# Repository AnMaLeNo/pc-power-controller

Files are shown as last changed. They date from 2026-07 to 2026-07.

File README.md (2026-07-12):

# 🔌 PC Power Controller (IoT)










Un système IoT complet permettant de contrôler à distance l'alimentation d'un PC fixe. Ce projet relie une interface de commande web/API à l'électronique physique de la carte mère du PC grâce à une architecture distribuée et conteneurisée.

## Description

Ce projet permet d'allumer, d'éteindre ou de forcer l'arrêt d'un ordinateur à distance en simulant une pression sur le bouton d'alimentation physique du boîtier. Il a été conçu avec une approche microservices pour garantir la fiabilité et la rapidité des commandes.

**Fonctionnalités principales :**
- **Contrôle physique sécurisé :** Utilisation d'un optocoupleur connecté à un ESP8266 pour isoler électriquement le circuit du microcontrôleur de celui de la carte mère.
- **Communication Temps Réel :** Utilisation d'un broker MQTT (Eclipse Mosquitto) pour transmettre les commandes de l'API vers le microcontrôleur presque instantanément.
- **API REST Robuste :** Développée avec Fastify pour des performances optimales, incluant la validation des schémas de requêtes.
- **Interface Web Typée :** Application React + TypeScript construite avec Vite, proposant un pupitre de commande adapté au contrôle physique du PC.
- **Déploiement Facilité :** Conteneurisation de la stack (Frontend + API) via Docker Compose. Le broker MQTT est une infrastructure partagée du Raspberry, hébergée dans son propre dépôt.

## Architecture du Système

Le projet est divisé en quatre composants majeurs :
1. **Frontend Web (React / TypeScript / Vite) :** Fournit une interface de commande responsive, servie par Nginx en production et reliée à l'API via un proxy `/api`.

2. **Backend API (Node.js / Fastify) :** Reçoit les requêtes HTTP (ex: `SHORT_PRESS` ou `LONG_PRESS`) et les publie sur le topic MQTT `bureau/pc/power/set`.
3. **Broker MQTT (Eclipse Mosquitto) :** Agit comme un intermédiaire léger pour distribuer les messages entre l'API et le hardware. C'est une infrastructure **partagée** entre tous les projets IoT du Raspberry (un seul broker par machine) : il vit dans le dépôt `~/mosquitto`, et ce projet s'y connecte en simple client via `host.docker.internal:1883` (surchargeable par `.env` : `MQTT_HOST`, `MQTT_PORT`).
4. **Firmware ESP8266 (C++ / Arduino) :** Connecté au réseau WiFi local, il s'abonne au topic MQTT. À la réception d'un message, il déclenche une impulsion (High/Low) d'une durée spécifique (300ms pour un appui court, 6000ms pour un appui long) sur la broche `D1` reliée à l'optocoupleur.

## Installation & Lancement

### 1. Configuration du Hardware (ESP8266)
Le code source se trouve dans le dossier `esp8266/`. Le projet est configuré avec **PlatformIO**.
- Copiez `config.ini.exemple` vers `config.ini` et ajoutez vos identifiants WiFi ainsi que l'IP de votre serveur MQTT.
- Compilez et téléversez le code C++ sur votre Wemos D1 Mini / ESP8266.

### 2. Prérequis : le broker MQTT partagé
Le broker Mosquitto n'est plus embarqué dans ce projet : c'est une infrastructure commune au Raspberry, gérée dans le dépôt `~/mosquitto`. Démarrez-le d'abord s'il ne tourne pas déjà :

```bash
cd ~/mosquitto
docker compose up -d
```

### 3. Lancement de la stack Docker
Assurez-vous d'avoir [Docker](https://www.docker.com/) et Docker Compose installés sur votre machine ou votre serveur cible (ex: Raspberry Pi).

```bash
# Clonez le dépôt
git clone https://github.com/AnMaLeNo/pc-power-controller.git
cd pc-power-controller

# Lancez les conteneurs en tâche de fond
docker compose up -d --build
```

L'interface web est disponible sur `http://localhost:18080`. En mode développement avec l'override Docker Compose, Vite est aussi exposé sur `http://localhost:5174`.

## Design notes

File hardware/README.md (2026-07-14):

# 🔧 Hardware — carte optocoupleur (KiCad)

PCB « carrier » compact (**54,7 × 35,2 mm**) pour le contrôleur
d'alimentation : un **Wemos D1 Mini** pilote un **PC817** à travers **R1
(330 Ω)** ; la sortie de l'optocoupleur va sur **2 pastilles à souder** (J1)
reliées par fils au header `PWR_SW` de la carte mère. Isolation galvanique
totale entre l'ESP8266 et le PC. Deux pastilles supplémentaires (**J2**)
permettent d'alimenter le module en 5 V sans passer par l'USB.

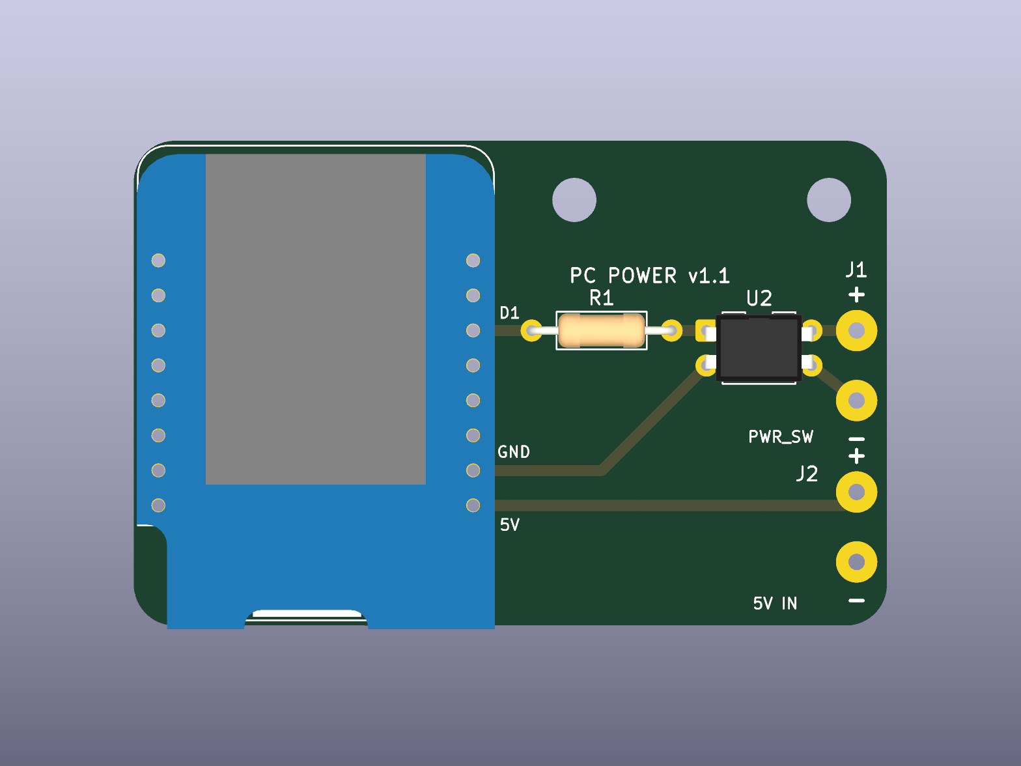
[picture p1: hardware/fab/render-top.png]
Rendu du dessus


## Contenu

| Fichier | Rôle |
|---|---|
| `pc-power-controller.kicad_pro/sch/pcb` | Projet KiCad (s'ouvre dans KiCad ≥ 9) |
| `pc_power.kicad_sym`, `pc_power.pretty/` | Symboles & empreintes du projet (copies figées des libs officielles 9.0.9.1) |
| `generate/gen_sch.py` | Génère le schéma (Python pur) |
| `generate/gen_pcb.py` | Génère le PCB routé (API `pcbnew` du flatpak KiCad) |
| `fab/` | Sorties : Gerbers + perçage (`pc-power-controller-gerbers.zip`), BOM, rendus, rapports ERC/DRC |

## Nomenclature (BOM)

| Réf. | Composant | Empreinte |
|---|---|---|
| U1 | Wemos D1 Mini (ESP8266) | 2 rangées de 8 broches, pas 2,54 mm — prévoir des **headers femelles** |
| U2 | PC817 (Sharp) | DIP-4 |
| R1 | Résistance 330 Ω, 1/4 W axiale | DIN0207, pas 10,16 mm |
| J1 | Sortie PWR_SW | 2 pastilles Ø3 mm, perçage 1,2 mm, pas 5,08 mm |
| J2 | Entrée alim 5V/GND | 2 pastilles Ø3 mm, perçage 1,2 mm, pas 5,08 mm |
| H1-H2 | Vis M3 | 2 trous de fixation Ø3,2 mm |

## Câblage vers le PC

**J1 (PWR_SW)** :
- Pastille **`+`** → broche `PWR_SW` (signal) du header F_PANEL de la carte mère
- Pastille **`−`** → broche `GND` du même header
- La polarité **compte** (collecteur/émetteur du PC817). En cas de doute : la
  broche `+` du header carte mère est celle qui n'est pas au GND du boîtier.

**Alimentation, au choix** :
- par le **port USB** du module (bord bas de la carte), **ou**
- par **J2** : pastille `+` → 5 V, pastille `−` → GND (ex. depuis le standby
  5VSB d'une alim ATX ou un chargeur sacrifié).
- ⚠️ **Jamais les deux en même temps** : la broche 5V du D1 Mini est reliée en
  direct au VBUS de l'USB (pas de diode sur la plupart des clones).

## Régénérer les fichiers

```bash
cd hardware
python3 generate/gen_sch.py
flatpak run --command=python3 org.kicad.KiCad generate/gen_pcb.py
```

## Vérifier et exporter

```bash
k="flatpak run --command=kicad-cli org.kicad.KiCad"
$k sch erc --severity-all --format report -o fab/erc.rpt pc-power-controller.kicad_sch
$k pcb drc --schematic-parity --severity-all --format report -o fab/drc.rpt pc-power-controller.kicad_pcb
$k pcb render --side top -o fab/render-top.png pc-power-controller.kicad_pcb
$k pcb export gerbers --layers F.Cu,B.Cu,F.Mask,B.Mask,F.SilkS,B.SilkS,Edge.Cuts -o fab/gerbers/ pc-power-controller.kicad_pcb
$k pcb export drill --format excellon --excellon-units mm --drill-origin absolute -o fab/gerbers/ pc-power-controller.kicad_pcb
```

État actuel : **ERC 0 erreur / 0 warning, DRC 0 violation, parité schéma↔PCB OK.**

## Commander (ex. JLCPCB)

1. <https://jlcpcb.com> → *Order now* → uploader `fab/pc-power-controller-gerbers.zip`
2. Paramètres par défaut : 2 couches, 1,6 mm, HASL — carte 54,7 × 35,2 mm
3. ~2-5 € les 5 exemplaires, hors port. Soudure à la main (tout traversant).

## Notes de conception

- Piste GND : pad 10 du module (7ᵉ pastille, colonne droite) ; signal : pad 14
  (`D1`/GPIO5, 3ᵉ pastille) — cohérent avec `esp8266/src/main.cpp` (`pinOpto = D1`).
- Le retour GND de J2 passe en **face arrière** (seule piste au dos) ; les pads
  traversants relient les deux couches, aucun via.
- La zone antenne du module (haut gauche) est **sans cuivre ni piste** ; ne
  rien ajouter dans cette zone si la carte évolue.
- Prévu pour un 2ᵉ étage plus tard (lecture de l'état d'alim du PC) : les
  GPIO restants du module sont accessibles sur les pastilles du support.

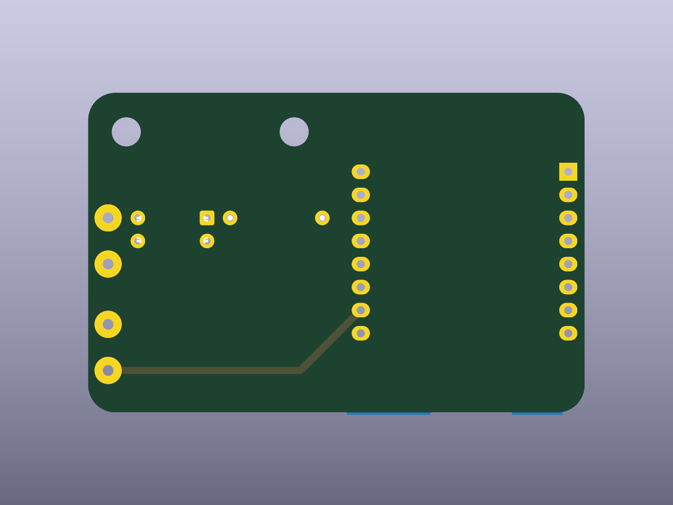
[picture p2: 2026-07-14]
hardware/fab/render-bottom.png

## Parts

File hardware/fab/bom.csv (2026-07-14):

Reference | Valeur | Empreinte | Qte
J1 | PWR_SW | pc_power:SolderWirePad_1x02_P5.08mm | 1
J2 | 5V_IN | pc_power:SolderWirePad_1x02_P5.08mm | 1
R1 | 330R | pc_power:R_Axial_DIN0207_L6.3mm_D2.5mm_P10.16mm_Horizontal | 1
U1 | WEMOS_D1_mini | pc_power:WEMOS_D1_mini_light | 1
U2 | PC817 | pc_power:DIP-4_W7.62mm | 1

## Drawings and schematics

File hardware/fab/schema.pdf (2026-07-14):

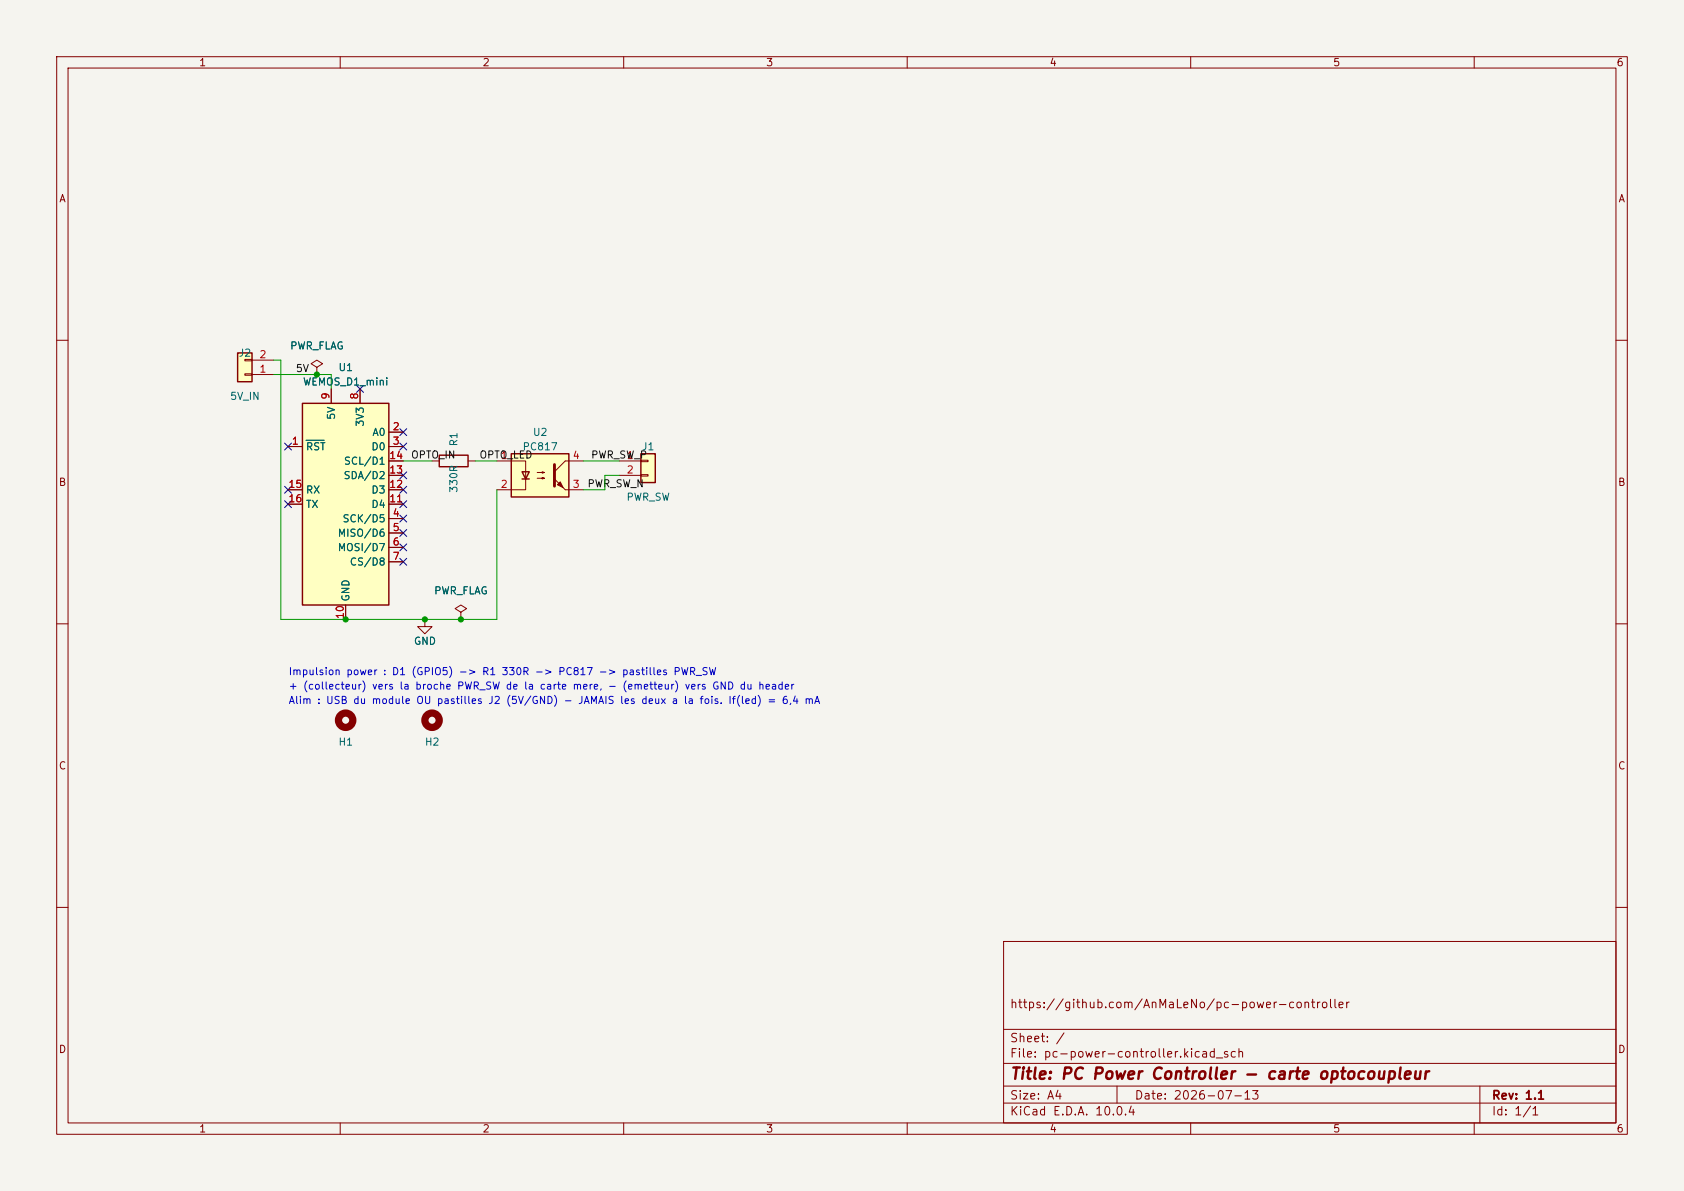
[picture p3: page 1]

Alim : USB du module OU pastilles J2 (5V/GND) - JAMAIS les deux a la fois. If(led) = 6,4 mA U1 WEMOS_D1_mini RST 1

8 5V 9 GND 10 D4 11 D3 12 SDA/D2 13 SCL/D1 14 RX 15

RST 1
PWR_SW_P + (collecteur) vers la broche PWR_SW de la carte mere, - (emetteur) vers GND du header

Sheet: /
File: pc-power-controller.kicad_sch
Title: PC Power Controller - carte optocoupleur

Size: A4 | Rev: 1.1
KiCad E.D.A. 10.0.4 | Id: 1/1

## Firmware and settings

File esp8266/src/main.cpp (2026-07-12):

#include <Arduino.h>
#include <ESP8266WiFi.h>
#include <PubSubClient.h>

// Configuration
const char* ssid = WIFI_SSID;
const char* password = WIFI_PASS;
const char* mqtt_server = MQTT_SERVER;
const uint16_t mqtt_port = 1883;

// Topiques MQTT
const char* topic_command = "bureau/pc/power/set";
const char* topic_state   = "bureau/pc/power/log";
// Présence : "online" publié à la connexion, "offline" déposé par le broker
// via le Last Will si la liaison meurt (~1,5x le keepalive). Retenu, pour que
// tout abonné connaisse l'état courant dès sa souscription.
const char* topic_status  = "bureau/pc/power/status";

// Hardware
const int pinOpto = D1;
const int pinLed = LED_BUILTIN;

WiFiClient wifiNetworkClient;
PubSubClient mqttClient(wifiNetworkClient);

// Impulsion matérielle : la fin est déléguée au timer1 (ISR one-shot), donc la
// durée reste bornée même si la boucle principale est bloquée (ex. connect()
// MQTT pendant une panne réseau). Contrainte : timer1 doit rester libre, donc
// pas d'analogWrite/tone/Servo dans ce firmware.
volatile bool pulseActive = false;
const uint32_t SHORT_PRESS_DURATION = 300;
const uint32_t LONG_PRESS_DURATION = 6000;
// Action en cours, corrélée à l'ACK pulse_end. Littéraux uniquement : l'ISR
// recopie le pointeur, jamais le contenu.
const char* pulseAction = "";
// Fin d'impulsion signalée par l'ISR ; l'ACK MQTT est publié depuis la boucle
// principale (interdiction de publier depuis une ISR).
const char* volatile endedAction = "";
volatile bool pulseEndPending = false;

// Définition des états de l'automate réseau (FSM)
enum NetworkState {
    NET_INIT,
    NET_WIFI_CONNECTING,
    NET_WIFI_WAIT,
    NET_MQTT_CONNECTING,
    NET_CONNECTED,
    NET_COOLDOWN
};

NetworkState netState = NET_INIT;
uint32_t lastNetworkAttempt = 0;
// Timeout d'association WiFi + DHCP : assez large pour les box lentes (sinon
// l'ESP abandonne avant la fin de la négociation et boucle indéfiniment).
const uint32_t WIFI_CONNECT_TIMEOUT = 20000;
// Délai de temporisation avant une nouvelle tentative après un échec.
const uint32_t COOLDOWN_DURATION = 5000;

// Dimensionné pour le plus long ACK JSON (pulse_start/end avec action + ts 32 bits).
char buffer[80];
const uint16_t MESSAGE_MAX_LENGTH = 20;

// Déclaration préalable des fonctions
void startPulse(uint32_t duration, const char* action);
void handlePulseAck();
void processNetworkFSM();

void callback(char* topic, byte* payload, unsigned int length) {
    char message[MESSAGE_MAX_LENGTH + 1];
    if (length > MESSAGE_MAX_LENGTH) {
        mqttClient.publish(topic_state, "{\"event\":\"error\",\"reason\":\"payload_too_large\"}");
        Serial.printf("payload trop grand, size: %d, max: %d\n", length, MESSAGE_MAX_LENGTH);
        return;
    }

    memcpy(message, payload, length);
    message[length] = '\0';
    Serial.printf("Message reçu [%s] %s\n", topic, message);

    if (strcmp(topic, topic_command) == 0) {
        if (strcmp(message, "SHORT_PRESS") == 0) {
            startPulse(SHORT_PRESS_DURATION, "SHORT_PRESS");
        } else if (strcmp(message, "LONG_PRESS") == 0) {
            startPulse(LONG_PRESS_DURATION, "LONG_PRESS");
        } else {
            mqttClient.publish(topic_state, "{\"event\":\"error\",\"reason\":\"unknown_command\"}");
            Serial.printf("Message [%s] inconnu\n", message);
        }
    }
}

// Fin d'impulsion en contexte d'interruption : s'exécute à l'échéance exacte,
// y compris pendant un appel réseau bloquant de la boucle principale.
IRAM_ATTR void onPulseEnd() {
    digitalWrite(pinOpto, LOW);
    digitalWrite(pinLed, HIGH);
    endedAction = pulseAction;
    pulseEndPending = true;
    pulseActive = false;
}

void startPulse(uint32_t duration, const char* action) {
    if (pulseActive) {
        mqttClient.publish(topic_state, "{\"event\":\"error\",\"reason\":\"pulse_already_active\"}");
        Serial.print("Pulse already active\n");
        return;
    }
    pulseAction = action;
    pulseActive = true;

    digitalWrite(pinOpto, HIGH);
    digitalWrite(pinLed, LOW);

    // One-shot timer1 en TIM_DIV256 : 80 MHz / 256 = 312,5 ticks/ms, d'où
    // ticks = ms * 625 / 2 (durées paires ici, division exacte). Max 23 bits
    // = ~26,8 s, largement au-dessus du LONG_PRESS.
    timer1_enable(TIM_DIV256, TIM_EDGE, TIM_SINGLE);
    timer1_write((duration * 625UL) / 2);

    // Publié après l'armement : un blocage réseau ne peut plus retarder la
    // libération de la broche, elle appartient désormais au timer.
    snprintf(buffer, sizeof(buffer),
             "{\"event\":\"pulse_start\",\"action\":\"%s\",\"ts\":%lu}", action, millis());
    mqttClient.publish(topic_state, buffer);
    Serial.print("Start pulse\n");
}

// Publie l'ACK de la fin d'impulsion signalée par l'ISR. Le ts est celui de la
// publication ; la broche, elle, a été libérée pile à l'échéance par le timer.
void handlePulseAck() {
    if (!pulseEndPending) return;
    pulseEndPending = false;

    if (mqttClient.connected()) {
        snprintf(buffer, sizeof(buffer),
                 "{\"event\":\"pulse_end\",\"action\":\"%s\",\"ts\":%lu}", endedAction, millis());
        mqttClient.publish(topic_state, buffer);
    }
    Serial.print("End pulse\n");
}

void processNetworkFSM() {
    uint32_t now = millis();

    switch (netState) {
        case NET_INIT:
            WiFi.persistent(false);
            WiFi.mode(WIFI_STA);
            WiFi.setAutoConnect(false);     // Désactivation de la FSM interne d'Espressif (L2)
            WiFi.setAutoReconnect(false);   // Reprise du contrôle logiciel absolu de la couche liaison
            netState = NET_WIFI_CONNECTING;
            break;

        case NET_WIFI_CONNECTING:
            Serial.printf("Connexion au WiFi: %s\n", ssid);
            WiFi.begin(ssid, password);
            lastNetworkAttempt = now;
            netState = NET_WIFI_WAIT;
            break;

        case NET_WIFI_WAIT:
            if (WiFi.status() == WL_CONNECTED) {
                Serial.printf("\nWiFi connecté. IP: %s\n", WiFi.localIP().toString().c_str());
                netState = NET_MQTT_CONNECTING;
            } else if (now - lastNetworkAttempt >= WIFI_CONNECT_TIMEOUT) {
                Serial.println("\nTimeout WiFi. Bascule en Cooldown.");
                WiFi.disconnect();
                lastNetworkAttempt = now;
                netState = NET_COOLDOWN;
            }
            break;

        case NET_MQTT_CONNECTING:
            if (WiFi.status() != WL_CONNECTED) {
                netState = NET_WIFI_CONNECTING;
                break;
            }

            {
                String clientId = "ESP8266Client-" + WiFi.macAddress();
                clientId.replace(":", "");
                Serial.printf("Tentative MQTT %s:%u\n", mqtt_server, mqtt_port);
                
                // Appel synchrone encapsulé - Blocage borné par le timeout LwIP/PubSubClient.
                // Le Last Will (QoS 1, retenu) est déposé auprès du broker à la connexion.
                if (mqttClient.connect(clientId.c_str(), topic_status, 1, true, "offline")) {
                    Serial.println("Connecté au serveur MQTT !");
                    // Message de naissance : annule l'éventuel "offline" retenu.
                    mqttClient.publish(topic_status, "online", true);
                    mqttClient.subscribe(topic_command);
                    netState = NET_CONNECTED;
                } else {
                    Serial.printf("Echec MQTT rc=%d. Bascule en Cooldown.\n", mqttClient.state());
                    lastNetworkAttempt = now;
                    netState = NET_COOLDOWN;
                }
            }
            break;

        case NET_CONNECTED:
            if (WiFi.status() != WL_CONNECTED || !mqttClient.connected()) {
                Serial.println("Perte de liaison (L2 ou L7).");
                netState = NET_COOLDOWN;
                lastNetworkAttempt = now;
            } else {
                mqttClient.loop(); // Traitement des buffers réseau entrants
            }
            break;

        case NET_COOLDOWN:
            // Interdiction stricte de toute opération réseau pendant la fenêtre de temporisation
            if (now - lastNetworkAttempt >= COOLDOWN_DURATION) {
                netState = (WiFi.status() == WL_CONNECTED) ? NET_MQTT_CONNECTING : NET_WIFI_CONNECTING;
            }
            break;
    }
}

void setup() {
    Serial.begin(115200);
    pinMode(pinOpto, OUTPUT);
    pinMode(pinLed, OUTPUT);
    
    // Initialisation de l'état nominal physique (Safe state)
    digitalWrite(pinOpto, LOW);
    digitalWrite(pinLed, HIGH);

    // Timer matériel dédié à la fin d'impulsion (one-shot armé par startPulse)
    timer1_isr_init();
    timer1_attachInterrupt(onPulseEnd);

    mqttClient.setServer(mqtt_server, mqtt_port);
    mqttClient.setCallback(callback);
}

void loop() {
    // Ordonnancement coopératif à complexité amortie O(1)
    handlePulseAck();      // Publication différée des ACK de fin d'impulsion
    processNetworkFSM();   // Traitement asynchrone non-bloquant du vecteur réseau
}

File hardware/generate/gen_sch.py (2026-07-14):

#!/usr/bin/env python3
"""Génère hardware/pc-power-controller.kicad_sch (format KiCad 9).

Circuit : D1 (GPIO5) -> R1 330R -> LED du PC817 ; sortie du PC817 -> 2 pastilles
à souder (PWR_SW) vers le header power de la carte mère.
Toutes les coordonnées sont en mm, alignées sur la grille 1,27 mm ; la
connectivité KiCad repose sur la coïncidence exacte des extrémités.
"""
import uuid
from pathlib import Path

HERE = Path(__file__).resolve().parent          # hardware/generate
HW = HERE.parent                                # hardware/
OUT = HW / "pc-power-controller.kicad_sch"
PROJECT = "pc-power-controller"


def uid(key: str) -> str:
    return str(uuid.uuid5(uuid.NAMESPACE_URL, "pc-power-sch/" + key))


ROOT = uid("root")


def sym_lib_bare(name: str) -> str:
    return (HERE / "symbols" / f"{name}.sym").read_text().rstrip()


def sym_lib(name: str) -> str:
    # dans le schéma, les symboles embarqués portent le préfixe de la lib projet
    return sym_lib_bare(name).replace('(symbol "', '(symbol "pc_power:', 1)


def wire(x1, y1, x2, y2, key):
    return f"""\t(wire
\t\t(pts
\t\t\t(xy {x1} {y1}) (xy {x2} {y2})
\t\t)
\t\t(stroke
\t\t\t(width 0)
\t\t\t(type default)
\t\t)
\t\t(uuid "{uid('wire/' + key)}")
\t)"""


def junction(x, y, key):
    return f"""\t(junction
\t\t(at {x} {y})
\t\t(diameter 0)
\t\t(color 0 0 0 0)
\t\t(uuid "{uid('junction/' + key)}")
\t)"""


def no_connect(x, y, key):
    return f"""\t(no_connect
\t\t(at {x} {y})
\t\t(uuid "{uid('nc/' + key)}")
\t)"""


def label(txt, x, y, key):
    return f"""\t(label "{txt}"
\t\t(at {x} {y} 0)
\t\t(effects
\t\t\t(font
\t\t\t\t(size 1.27 1.27)
\t\t\t)
\t\t\t(justify left bottom)
\t\t)
\t\t(uuid "{uid('label/' + key)}")
\t)"""


def text(txt, x, y, key):
    return f"""\t(text "{txt}"
\t\t(exclude_from_sim no)
\t\t(at {x} {y} 0)
\t\t(effects
\t\t\t(font
\t\t\t\t(size 1.27 1.27)
\t\t\t)
\t\t\t(justify left bottom)
\t\t)
\t\t(uuid "{uid('text/' + key)}")
\t)"""


def prop(name, value, x, y, rot=0, hide=False):
    h = "\n\t\t\t\t(hide yes)" if hide else ""
    return f"""\t\t(property "{name}" "{value}"
\t\t\t(at {x} {y} {rot})
\t\t\t(effects
\t\t\t\t(font
\t\t\t\t\t(size 1.27 1.27)
\t\t\t\t){h}
\t\t\t)
\t\t)"""


def symbol(lib_id, ref, x, y, rot, props, pins, key, in_bom=True):
    pin_stubs = "\n".join(
        f'\t\t(pin "{n}"\n\t\t\t(uuid "{uid(key + "/pin" + n)}")\n\t\t)' for n in pins
    )
    if pin_stubs:
        pin_stubs += "\n"
    return f"""\t(symbol
\t\t(lib_id "{lib_id}")
\t\t(at {x} {y} {rot})
\t\t(unit 1)
\t\t(exclude_from_sim no)
\t\t(in_bom {"yes" if in_bom else "no"})
\t\t(on_board yes)
\t\t(dnp no)
\t\t(uuid "{uid(key)}")
{props}
{pin_stubs}\t\t(instances
\t\t\t(project "{PROJECT}"
\t\t\t\t(path "/{ROOT}"
\t\t\t\t\t(reference "{ref}")
\t\t\t\t\t(unit 1)
\t\t\t\t)
\t\t\t)
\t\t)
\t)"""


body = []

# ---------------------------------------------------------------- U1 D1 mini
# Ancré en (60.96, 88.90) rot 0. Pin D1/GPIO5 = n°14 -> (71.12, 81.28),
# GND = n°10 -> (60.96, 109.22).
body.append(symbol(
    "pc_power:WEMOS_D1_mini", "U1", 60.96, 88.90, 0,
    "\n".join([
        prop("Reference", "U1", 60.96, 64.77),
        prop("Value", "WEMOS_D1_mini", 60.96, 67.31),
        prop("Footprint", "pc_power:WEMOS_D1_mini_light", 60.96, 88.90, hide=True),
        prop("Datasheet", "https://wiki.wemos.cc/products:d1:d1_mini", 60.96, 88.90, hide=True),
    ]),
    [str(n) for n in range(1, 17)],
    "sym/U1",
))

# Broches inutilisées du module -> croix "no connect"
for px, py, k in [
    (50.80, 78.74, "u1-1-rst"), (71.12, 76.20, "u1-2-a0"), (71.12, 78.74, "u1-3-d0"),
    (71.12, 91.44, "u1-4-d5"), (71.12, 93.98, "u1-5-d6"), (71.12, 96.52, "u1-6-d7"),
    (71.12, 99.06, "u1-7-d8"), (63.50, 68.58, "u1-8-3v3"),
    (71.12, 88.90, "u1-11-d4"), (71.12, 86.36, "u1-12-d3"), (71.12, 83.82, "u1-13-d2"),
    (50.80, 86.36, "u1-15-rx"), (50.80, 88.90, "u1-16-tx"),
]:
    body.append(no_connect(px, py, k))

# ------------------------------------------------------------------- R1 330R
# Rot 90 -> horizontale : pin 1 en (76.20, 81.28), pin 2 en (83.82, 81.28)
body.append(symbol(
    "pc_power:R", "R1", 80.01, 81.28, 90,
    "\n".join([
        prop("Reference", "R1", 80.01, 77.47),
        prop("Value", "330R", 80.01, 84.455),
        prop("Footprint", "pc_power:R_Axial_DIN0207_L6.3mm_D2.5mm_P10.16mm_Horizontal", 80.01, 81.28, 90, hide=True),
        prop("Datasheet", "~", 80.01, 81.28, hide=True),
    ]),
    ["1", "2"],
    "sym/R1",
))

# -------------------------------------------------------------------- U2 PC817
# Pins : 1 anode (87.63, 81.28), 2 cathode (87.63, 86.36),
#        3 émetteur (102.87, 86.36), 4 collecteur (102.87, 81.28)
body.append(symbol(
    "pc_power:PC817", "U2", 95.25, 83.82, 0,
    "\n".join([
        prop("Reference", "U2", 95.25, 76.20),
        prop("Value", "PC817", 95.25, 78.74),
        prop("Footprint", "pc_power:DIP-4_W7.62mm", 95.25, 83.82, hide=True),
        prop("Datasheet", "http://www.soselectronic.cz/a_info/resource/d/pc817.pdf", 95.25, 83.82, hide=True),
    ]),
    ["1", "2", "3", "4"],
    "sym/U2",
))

# ------------------------------------------------- J1 pastilles à souder PWR_SW
# Pins : 1 en (109.22, 81.28), 2 en (109.22, 83.82)
body.append(symbol(
    "pc_power:Conn_01x02", "J1", 114.30, 81.28, 0,
    "\n".join([
        prop("Reference", "J1", 114.30, 78.74),
        prop("Value", "PWR_SW", 114.30, 87.63),
        prop("Footprint", "pc_power:SolderWirePad_1x02_P5.08mm", 114.30, 81.28, hide=True),
        prop("Datasheet", "~", 114.30, 81.28, hide=True),
    ]),
    ["1", "2"],
    "sym/J1",
))

# --------------------------------------------- J2 pastilles alimentation 5V/GND
# Rot 180 -> broches à droite : 1 (5V) en (48.26, 66.04), 2 (GND) en (48.26, 63.5)
body.append(symbol(
    "pc_power:Conn_01x02", "J2", 43.18, 66.04, 180,
    "\n".join([
        prop("Reference", "J2", 43.18, 62.23),
        prop("Value", "5V_IN", 43.18, 69.85),
        prop("Footprint", "pc_power:SolderWirePad_1x02_P5.08mm", 43.18, 66.04, hide=True),
        prop("Datasheet", "~", 43.18, 66.04, hide=True),
    ]),
    ["1", "2"],
    "sym/J2",
))
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

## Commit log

2026-03-30 feat(api): scaffold Fastify REST API with MQTT client Set up a Node.js/Fastify server that: - connects to the MQTT broker - exposes POST /api/power to publish SHORT_PRESS/LONG_PRESS commands - valida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
2026-03-30 build(api): add multi-stage Dockerfile for dev and prod - Base stage: Node 24-alpine, non-root user (node) - Development stage: npm ci + hot-reload via --watch - Production stage: npm ci --only=produ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
2026-03-30 build(docker): add Docker Compose orchestration Configure services: - mosquitto: Eclipse Mosquitto 2.1 on alpine, port 1883 - api: Fastify API built from power-pc-api/, production target - Isolated b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
2026-03-30 feat(firmware): add ESP8266 PlatformIO firmware Non-blocking power button controller over MQTT: - WiFi auto-reconnect - MQTT subscription on bureau/pc/power/set - SHORT_PRESS (300ms) and LONG_PRESS (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
    [main.cpp]
2026-05-19 feat(frontend): add web power control panel
2026-06-07 feat(compose): add healthchecks and readiness-gated startup
    - api: expose lightweight GET /health that reflects MQTT connectivity
    (200 ok / 503 degraded), probed via node http (no extra dependency)
    - mosquitto: healthcheck via mosquitto_sub on $SYS/# with timeout
    - frontend: healthcheck via wget on the nginx root
    - depends_on now uses condition: service_healthy so each service waits
    for its dependency to be actually ready, not just created
2026-06-07 feat(compose): add start_interval to healthchecks for faster readiness
    Following review feedback: during start_period Docker probes at the
    default 'interval' cadence (10s here), so a service ready in ~1s is
    only detected up to 10s later. start_interval: 1s makes Docker probe
    every second during the startup window and flip the container to
    healthy as soon as it is actually ready, speeding up the
    service_healthy dependency chain at boot.
    Requires Docker Engine >= 25 (host runs 29.5.3).
2026-06-08 fix(firmware): split WiFi connect timeout from cooldown (fix connection loop)
    The single NETWORK_TIMEOUT (5000ms) was used both as the WiFi
    association deadline and the cooldown duration. 5s is too short for
    WiFi + DHCP negotiation on some routers (e.g. Freebox): the FSM
    declared a timeout and disconnected right before the association
    completed, looping forever on 'Timeout WiFi. Bascule en Cooldown.'
    - WIFI_CONNECT_TIMEOUT = 20000: leaves enough time for association+DHCP
    - COOLDOWN_DURATION = 5000: keeps retries reactive after a failure
    Validated on real hardware (Wemos D1 mini): connects to WiFi and MQTT
    reliably after the change.
    [main.cpp]
2026-06-08 style(firmware): fix typo MESSAGE_MAX_LENGHT -> MESSAGE_MAX_LENGTH
    [main.cpp]
2026-06-08 feat: end-to-end ACK via SSE from ESP device feedback
    Closes the feedback loop: the ESP already publishes pulse events on
    bureau/pc/power/log, but nothing consumed them. The frontend journal
    was purely client-side and never reflected real device state.
    - api: subscribe to bureau/pc/power/log and relay every message to
    connected clients over a new GET /api/events SSE stream (text/
    event-stream, native http, no extra dependency). Graceful shutdown
    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
2026-06-08 fix(nginx): reduce SSE proxy_read_timeout from 24h to 1h
    Un timeout de 24h laissait les connexions zombies (clients partis sans
    fermeture TCP propre : onglet crashé, coupure réseau) squatter une
    ressource pendant une journée entière. 1h borne ce gaspillage tout en
    restant transparent pour les connexions vivantes, qui sont maintenues
    par le heartbeat SSE applicatif.
    Répond à la review sur la PR #3.
2026-06-08 feat(api): add 30s SSE heartbeat to detect zombie connections
    Un client qui disparaît sans fermeture TCP propre (onglet crashé,
    coupure réseau) laissait sa connexion SSE ouverte côté serveur jusqu'au
    timeout nginx. Le heartbeat émet un commentaire SSE (`: ping`, ignoré
    par EventSource) toutes les 30s : l'écriture échoue sur un client mort,
    ce qui déclenche la détection de déconnexion, et maintient les
    connexions vivantes à travers les proxies.
    Un seul interval global (pas un timer par client), unref() pour ne pas
    bloquer l'arrêt du process, et clearInterval() au shutdown gracieux.
    Testé: flux SSE reçoit bien le heartbeat à ~30s.
2026-06-10 feat(firmware): publish structured JSON ACK instead of free text
    L ESP publiait des chaines de texte libres sur bureau/pc/power/log
    (\"Start pulse at N\", \"Pulse already active\"...), difficiles a typer
    cote applicatif. Il publie desormais un JSON structure:
    {\"event\":\"pulse_start\",\"action\":\"SHORT_PRESS\",\"ts\":12345}
    {\"event\":\"pulse_end\",\"action\":\"SHORT_PRESS\",\"ts\":12645}
    {\"event\":\"error\",\"reason\":\"pulse_already_active\"}
    {\"event\":\"error\",\"reason\":\"unknown_command\"}
    {\"event\":\"error\",\"reason\":\"payload_too_large\"}
    L action est propagee jusqu a startPulse/handlePulse pour correler
    pulse_end a la commande d origine. JSON construit par snprint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
    [main.cpp]
2026-06-10 feat(api): parse ESP JSON ACK into structured SSE events
    L API decode desormais le JSON publie par l ESP sur le topic log et
    relaie un objet type ({event, action?, ts?, reason?, timestamp}) au
    front via SSE, au lieu d une simple string {message}. C est le role de
    la couche d integration de normaliser le format du device.
    Fallback robuste: un payload non-JSON (ancien firmware non encore
    reflashe) est relaye en {event:"raw", message:<texte>} pour ne pas
    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
2026-06-10 feat(frontend): consume structured ESP events with typed labels
    Le panneau "Retours du PC" affiche desormais des libelles lisibles
    derives du JSON structure (ex. "Impulsion demarree — Appui court" au
    lieu de "Start pulse at 12345"), et distingue visuellement les erreurs
    (icone + style error) des evenements normaux.
    describeEspEvent() mappe event/action/reason vers un libelle FR; les
    raisons d erreur connues (pulse_already_active, unknown_command,
    payload_too_large) ont un texte dedie. Fallback sur event:"raw" pour
    tout payload non structure.
    Refs #4
2026-06-10 fix(compose): use 127.0.0.1 in frontend healthcheck (IPv4)
    Le healthcheck du frontend utilisait http://localhost:5173/. Dans le
    conteneur, busybox wget resout localhost en ::1 (IPv6) en premier, or
    nginx n ecoute qu en IPv4 (0.0.0.0:5173) -> connexion refusee -> le
    conteneur etait marque unhealthy alors que nginx servait parfaitement.
    Consequence concrete: Traefik ne route que les services healthy, donc
    le frontend etait injoignable derriere le reverse proxy (404).
    Fix: cibler 127.0.0.1 explicitement. Verifie par execution reelle:
    le conteneur passe healthy en ~4s et Traefik route (HTTP 200).
2026-06-10 docs(compose): condense healthcheck comment to one line
    Le diagnostic complet vit dans la description de la PR; on garde juste
    une ligne expliquant le pourquoi de 127.0.0.1 pour eviter une
    regression (un futur contributeur remettant localhost).
2026-06-10 docs(compose): reword healthcheck comment to name the real cause
    Le commentaire precedent ("nginx n ecoute qu en IPv4") laissait penser
    a un defaut de nginx. La vraie raison est qu un healthcheck doit cibler
    une IP litterale pour etre deterministe, independamment du bind nginx:
    localhost dependrait de l ordre de resolution IPv4/IPv6, fragile selon
    l image de base. Reformule en consequence.
2026-07-12 refactor(compose): consommer le broker MQTT partagé du Raspberry
    Mosquitto n'est plus embarqué dans la stack : il vit dans son propre
    dépôt d'infrastructure (~/mosquitto), unique pour toute la machine.
    L'API s'y connecte en simple client via host.docker.internal:1883
    (extra_hosts host-gateway), surchargeable par .env (MQTT_HOST,
    MQTT_PORT). Suppression du service mosquitto, de sa config et du
    depends_on associé ; README mis à jour en conséquence.
2026-07-12 fix(wifi): désactivation persistance flash pour éviter son usure
    [main.cpp]
2026-07-12 fix(esp8266): borner l'impulsion par le timer matériel (timer1)
    La fin d'impulsion était pilotée par millis() dans loop() : un
    mqttClient.connect() bloquant (5-15 s si le broker est injoignable)
    pouvait étirer un LONG_PRESS jusqu'à ~10 s au lieu de 6. La libération
    de la broche est désormais faite par l'ISR one-shot de timer1
    (TIM_DIV256, 312,5 ticks/ms) : la durée est garantie quel que soit
    l'état de la boucle principale. loop() ne fait plus que publier l'ACK
    pulse_end signalé par l'ISR. Contrainte documentée : timer1 doit
    rester libre (pas d'analogWrite/tone/Servo dans ce firmware).
    [main.cpp]
2026-07-12 feat(esp8266): présence du contrôleur via Last Will MQTT
    Dépose un testament "offline" (QoS 1, retenu) sur
    bureau/pc/power/status à la connexion et publie "online" (retenu) en
    message de naissance. Le broker bascule le topic à "offline" de
    lui-même si l'ESP disparaît sans se déconnecter proprement (timeout
    keepalive). Le flag retained garantit que tout client — API comprise —
    connaît l'état courant dès sa souscription, même s'il arrive après
    coup.
    [main.cpp]
2026-07-12 feat(api): relayer la présence du contrôleur en SSE
    S'abonne à bureau/pc/power/status (online/offline, retenu par le
    broker) en plus du topic log, mémorise le dernier état et le relaie
    aux navigateurs sous forme d'événement {event:"status", online}. Le
    dernier état connu est poussé immédiatement à chaque client SSE qui se
    connecte, pour que l'UI démarre synchronisée. Factorisation de la
    diffusion SSE dans un helper broadcast().
2026-07-12 feat(frontend): pastille de présence du contrôleur
    Affiche dans la barre supérieure l'état du contrôleur ESP (événement
    SSE status produit par l'API depuis le Last Will MQTT) : point vert en
    ligne, rouge hors ligne, neutre tant qu'aucun état retenu n'existe.
    L'UI distingue désormais "le flux temps réel fonctionne" de "le
    matériel est vraiment là".
2026-07-12 fix(frontend): écran blanc en HTTP — crypto.randomUUID indisponible
    Même bug latent que celui découvert sur fan_controller :
    crypto.randomUUID() n'existe qu'en contexte sécurisé (HTTPS ou
    localhost), donc l'UI servie en HTTP via l'IP du Raspberry plantait en
    créant une entrée de journal (commande envoyée, puis écran blanc).
    Identifiants remplacés par un compteur horodaté local, suffisant pour
    des clés React à unicité par session.
2026-07-14 Migre le frontend vers ARUIDS
    Le thème, le flux SSE, le cycle de commande et tous les composants
    partagés (topbar, pastilles, panneaux, journaux, modale de
    confirmation) viennent désormais du design system ARUIDS
    (github.com/AnMaLeNo/aruids, épinglé en v0.1.1).
    - App.tsx : useTheme / useDeviceStream / useCommand remplacent la
    plomberie locale ; la modale de confirmation devient le composant
    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
2026-07-14 feat(hardware): PCB v1.0 de la carte optocoupleur (KiCad, généré par code)
    Carte 62x46.5mm : Wemos D1 Mini + PC817 + R 330R + 2 pastilles PWR_SW.
    Schéma et PCB générés par generate/gen_sch.py et generate/gen_pcb.py
    (API pcbnew du flatpak KiCad 10). ERC/DRC 0 erreur, parité schéma-PCB OK.
    Bibliothèques officielles épinglées au tag 9.0.9.1. Gerbers prêts pour
    fabrication dans fab/.
    [bom.csv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]
2026-07-14 feat(hardware): PCB v1.1 — carte compacte + alimentation 5V/GND par pastilles
    Réduction de 62x46.5 à 54.7x35.2 mm (-40% de surface) : composants
    resserrés sur la ligne de D1, trous de fixation ramenés à 2 sur le
    bandeau haut. Ajout de J2 (2 pastilles Ø3 mm comme J1) pour alimenter
    le module en 5V/GND sans USB — retour GND routé en face arrière.
    Extrémités de pistes désormais dérivées des positions réelles des pads.
    ERC/DRC 0 erreur, parité schéma-PCB OK, Gerbers régénérés.
    [bom.csv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]
